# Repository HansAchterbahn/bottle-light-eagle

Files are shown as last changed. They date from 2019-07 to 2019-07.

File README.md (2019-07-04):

# Bottle Light: Eagle Data (PCB)

Bottle Light is a coaster that make your bottle glow in all colors of the rainbow. More information about the Bottle Light project can be found in the main repository: [bottle-light](https://github.com/HansAchterbahn/bottle-light)

In this Repository you can find the shematics and board layouts created in Eagle.

*Fork me and have fun!*

## Schematic

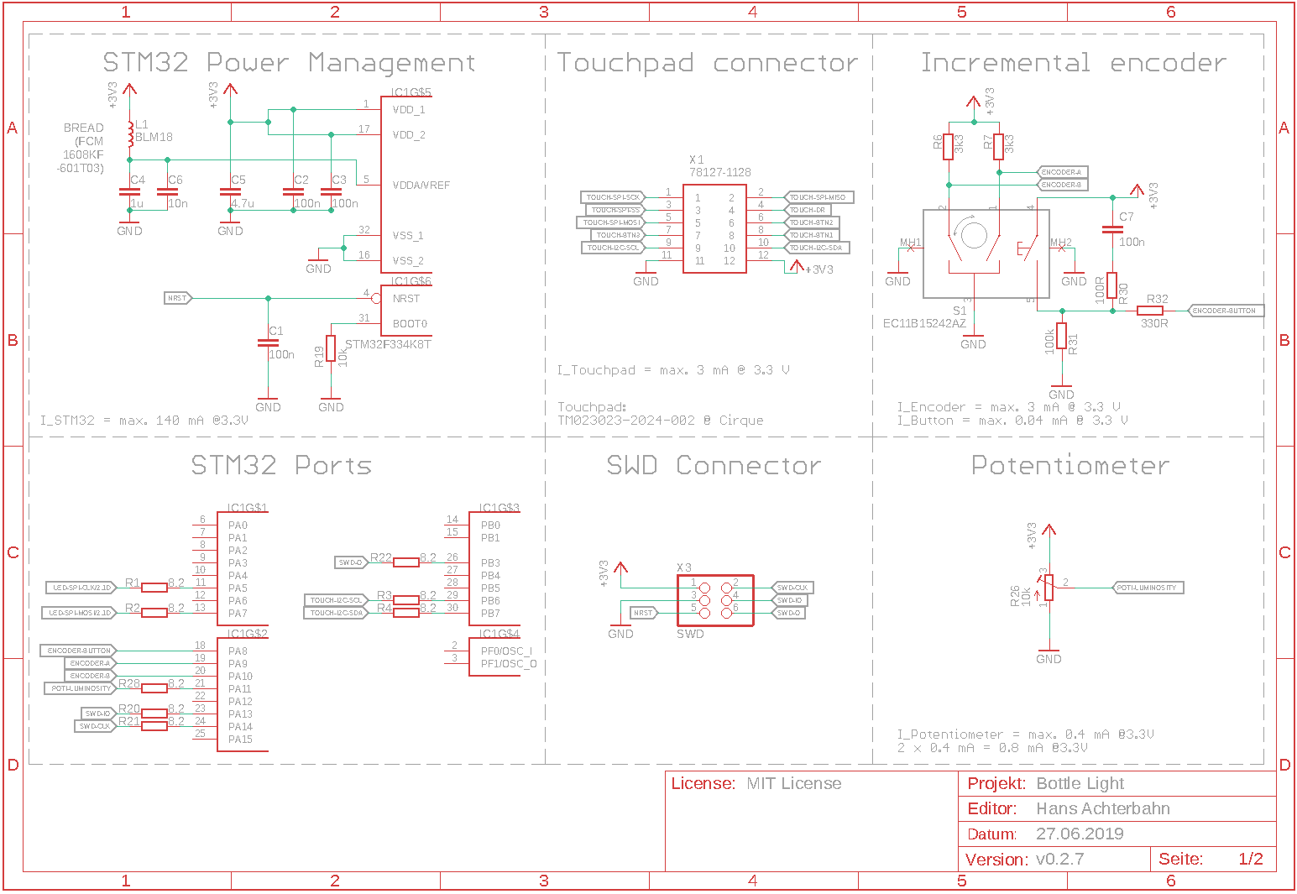
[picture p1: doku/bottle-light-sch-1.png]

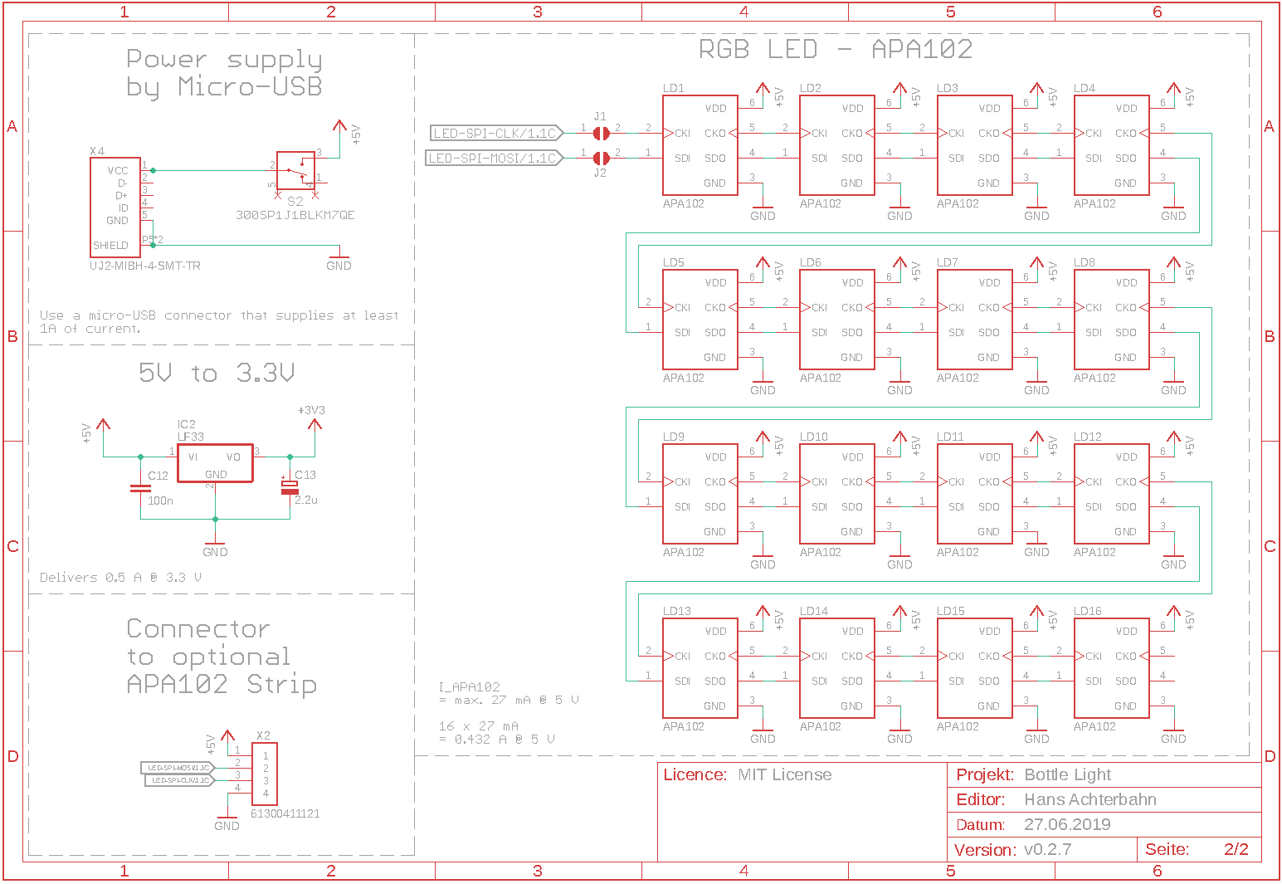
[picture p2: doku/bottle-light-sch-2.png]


## Board

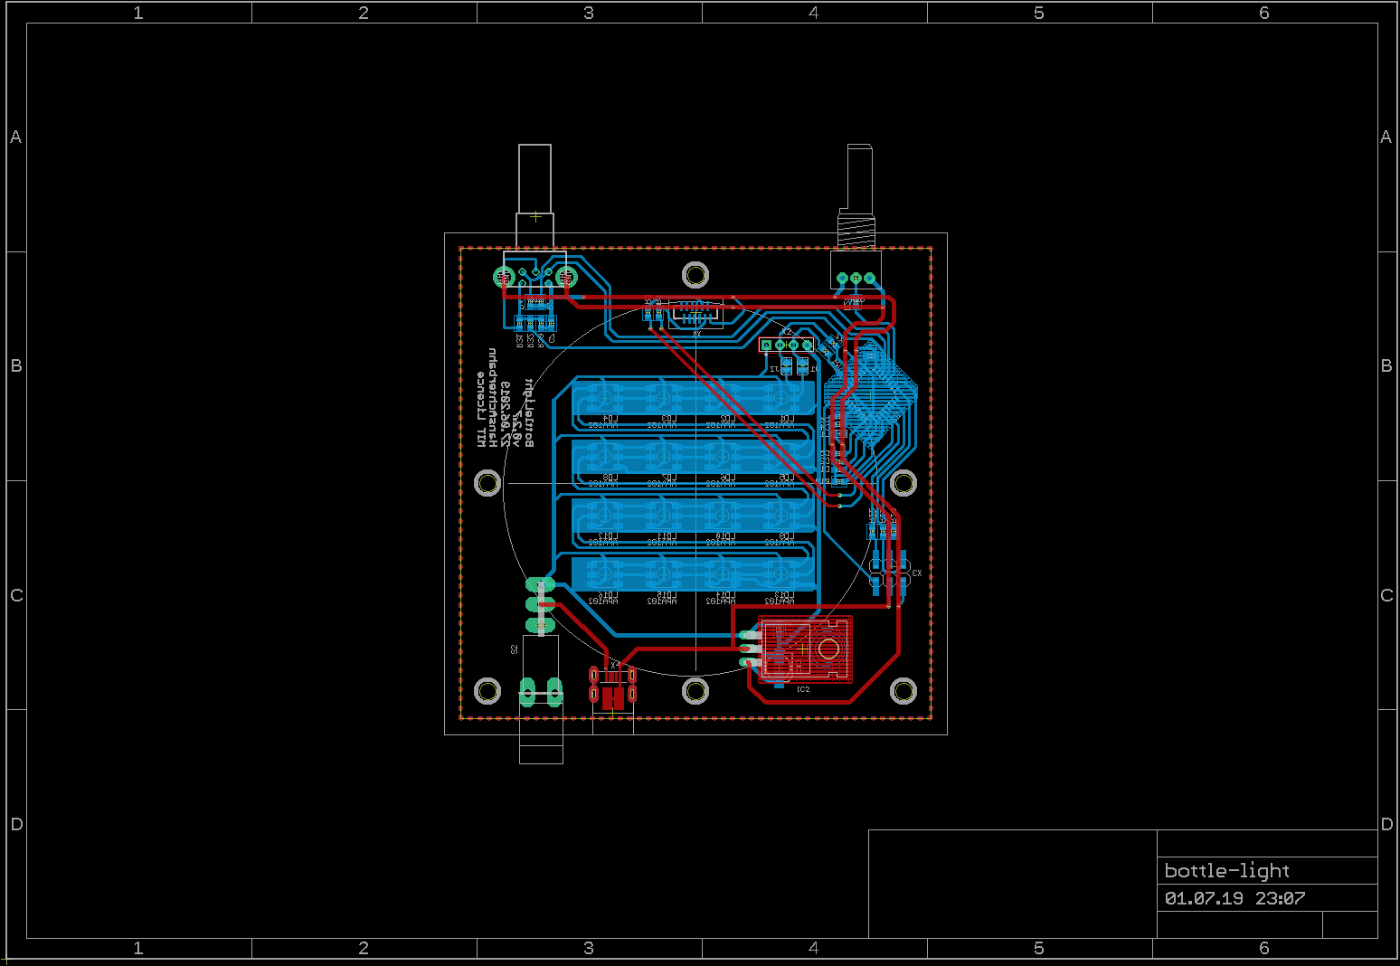
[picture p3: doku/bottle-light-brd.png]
LED Ring Board
 

## 3D View (Fusion360)

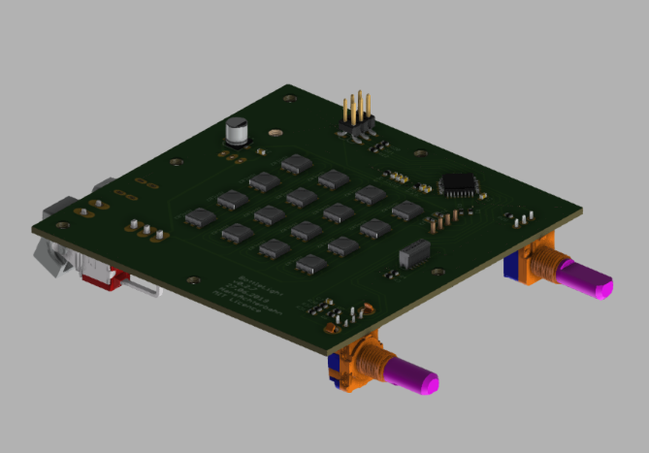
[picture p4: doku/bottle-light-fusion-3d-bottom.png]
LED Ring 3D top site

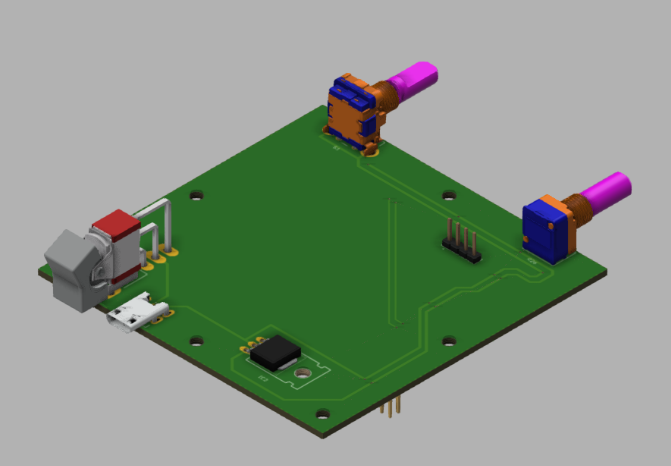
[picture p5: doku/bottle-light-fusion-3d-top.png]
LED Ring 3D bottom site


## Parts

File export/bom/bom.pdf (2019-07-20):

bom

Qty | Value | Parts | MF | MFN | MOUSER | RS-ONLINE
2 | | J1, J2
1 100R | | R30 | Vishay | CRCW0603100RFKEAHP | 71-CRCW0603-100-E3 | 820-6748
1 100k | | R31 | Vishay | CRCW0603100KFKEA | 71-CRCW0603-100K-E3 | 678-9673
1 100n | | C7 | AVX | 0603YC104JAT2A | 581-0603YC104J | 391-246
1 100n | | C12
3 100n | | C1, C2, C3 | | | | 391-246
1 10k | | R19
1 10k | | R26 | ALPS | RK097111080R | 688-RK097111080R | 729-3458
1 10n | | C6 | | | | 264-4595
1 1u | | C4 | | | | 435-1403
1 2.2u | | C13
1 300SP1J1BLKM7QE | | S2 | E-Switch | 300SP1J1BLKM7QE | 612-300SP1J1BLKM7QE | -
1 330R | | R32 | Vishay | CRCW0603330RFKEA | 71-CRCW0603-330-E3 | 679-0226
2 3k3 | | R6, R7 | Vishay | CRCW06032K70FKEAC | 71-CRCW06032K70FKEAC-
1 4.7u | | C5 | | | | 691-1164
1 | 61300411121 X2 | | | 61300411121
1 78127-1128 | | X1 | Molex | 78127-1128 | 538-78127-1128
8 8.2 | | R1, R2, R3, R4, R20, R21, R22, R28 | | | | 904-5027
16 APA102 | | LD1 … LD16
1 BLM18 | | L1 | Murata | BLM18KG601SN1D | 81-BLM18KG601SN1D | 747-4720
1 EC11B15242AZ | | S1 | ALPS | EC11B15242AZ | 688-EC11B15242AE
1 LF33 | | IC2
1 STM32F334K8T | | IC1 | ST | STM32F334K8T
1 SWD | | X3 | Harwin | M20-8760342 | 855-M20-8760342 | 681-2880
1 UJ2-MIBH-4-SMT-TR | | X4

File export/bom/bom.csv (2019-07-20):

Qty | Value | Device | Package | Parts | Description | ALLIED_NUMBER | ALLIED_PRICE-STOCK | CREATED_BY | DESCRIPTION | DIGI_KEY_PART_NUMBER | HEIGHT | MANUFACTURER | MF | MFN | MOUSER | RS-ONLINE
2 |  | SJ | SJ | J1, J2 | SMD solder JUMPER
1 | 100R | R-EU_R0603 | R0603 | R30 | RESISTOR, European symbol |  |  |  |  |  |  |  | Vishay | CRCW0603100RFKEAHP | 71-CRCW0603-100-E3 | 820-6748
1 | 100k | R-EU_R0603 | R0603 | R31 | RESISTOR, European symbol |  |  |  |  |  |  |  | Vishay | CRCW0603100KFKEA | 71-CRCW0603-100K-E3 | 678-9673
1 | 100n | C-EUC0603 | C0603 | C7 | CAPACITOR, European symbol |  |  |  |  |  |  |  | AVX | 0603YC104JAT2A | 581-0603YC104J | 391-246
1 | 100n | C-EUC0603 | C0603 | C12 | CAPACITOR, European symbol
3 | 100n | C-EUC0603K | C0603K | C1, C2, C3 | CAPACITOR, European symbol |  |  |  |  |  |  |  |  |  |  | 391-246
1 | 10k | R-EU_R0603 | R0603 | R19 | RESISTOR, European symbol
1 | 10k | RK0971110 | RK0971110 | R26 | Potentiometer |  |  |  |  |  |  |  | ALPS | RK097111080R | 688-RK097111080R | 729-3458
1 | 10n | C-EUC0603K | C0603K | C6 | CAPACITOR, European symbol |  |  |  |  |  |  |  |  |  |  | 264-4595
1 | 1u | C-EUC0603K | C0603K | C4 | CAPACITOR, European symbol |  |  |  |  |  |  |  |  |  |  | 435-1403
1 | 2.2u | CPOL-EU153CLV-0505 | 153CLV-0505 | C13 | POLARIZED CAPACITOR, European symbol
1 | 300SP1J1BLKM7QE | 300SP1J1BLKM7QE | 300SP1J1BLKM7QE | S2 | E-Switch - 300 Series Rocker Switch |  |  |  |  |  |  |  | E-Switch | 300SP1J1BLKM7QE | 612-300SP1J1BLKM7QE | -
1 | 330R | R-EU_R0603 | R0603 | R32 | RESISTOR, European symbol |  |  |  |  |  |  |  | Vishay | CRCW0603330RFKEA | 71-CRCW0603-330-E3 | 679-0226
2 | 3k3 | R-EU_R0603 | R0603 | R6, R7 | RESISTOR, European symbol |  |  |  |  |  |  |  | Vishay | CRCW06032K70FKEAC | 71-CRCW06032K70FKEAC | -
1 | 4.7u | C-EUC0603K | C0603K | C5 | CAPACITOR, European symbol |  |  |  |  |  |  |  |  |  |  | 691-1164
1 | 61300411121 | 61300411121 | 61300411121 | X2 | CONN HEADER VERT 4POS 2.54MM |  |  | PCBLayout.com |  | 732-5317-ND |  | Wurth Electronics Inc. |  | 61300411121
1 | 78127-1128 | 78127-1128 | 781271128 | X1 | FFC & FPC Connectors 0.5 FPC CONN. VERTIC AL SMT NON-ZIF 12CKT | 70714305 | https://www.alliedelec.com/molex-incorporated-78127-1128/70714305/ |  | FFC & FPC Connectors 0.5 FPC CONN. VERTIC AL SMT NON-ZIF 12CKT |  | 4mm |  | Molex | 78127-1128 | 538-78127-1128
8 | 8.2 | R-EU_R0603 | R0603 | R1, R2, R3, R4, R20, R21, R22, R28 | RESISTOR, European symbol |  |  |  |  |  |  |  |  |  |  | 904-5027
16 | APA102 | APA102APA102C-5050 | APA102C-5050 | LD1 … LD16 | DotStar Micro LEDs (APA102–2020)- Smart SMD RGB LED - 100 pack
1 | BLM18 | INDUCTOR/FERRITE-BEAD'0603' | L0603 | L1 |  |  |  |  |  |  |  |  | Murata | BLM18KG601SN1D | 81-BLM18KG601SN1D | 747-4720
1 | EC11B15242AZ | EC11B15242AZ | EC11B15242AZ | S1 | Komponente von www.SamacSys.com geforkt: |  |  |  | Encoders 5 Volts Through Hole |  | 24mm |  | ALPS | EC11B15242AZ | 688-EC11B15242AE
1 | LF33 | 7805T | TO220H | IC2 | Positive VOLTAGE REGULATOR
1 | STM32F334K8T | STM32F334K8T | LQFP32-7X7 | IC1 | STM32 Mikrocontroller: STM32F334K8Tx |  |  |  |  |  |  |  | ST | STM32F334K8T
1 | SWD | PINHD-2X3_2.54-SMD | 2X03SMD | X3 | PIN HEADER |  |  |  |  |  |  |  | Harwin | M20-8760342 | 855-M20-8760342 | 681-2880
1 | UJ2-MIBH-4-SMT-TR | UJ2-MIBH-4-SMT-TRCUIINC_UJ2-MIBH-4-SMT-TR-2 | CUIINC_UJ2-MIBH-4-SMT-TR-2 | X4 | Micro B Type 5 Pin Horizontal 30 µin Plating SMT USB Jack 2.0

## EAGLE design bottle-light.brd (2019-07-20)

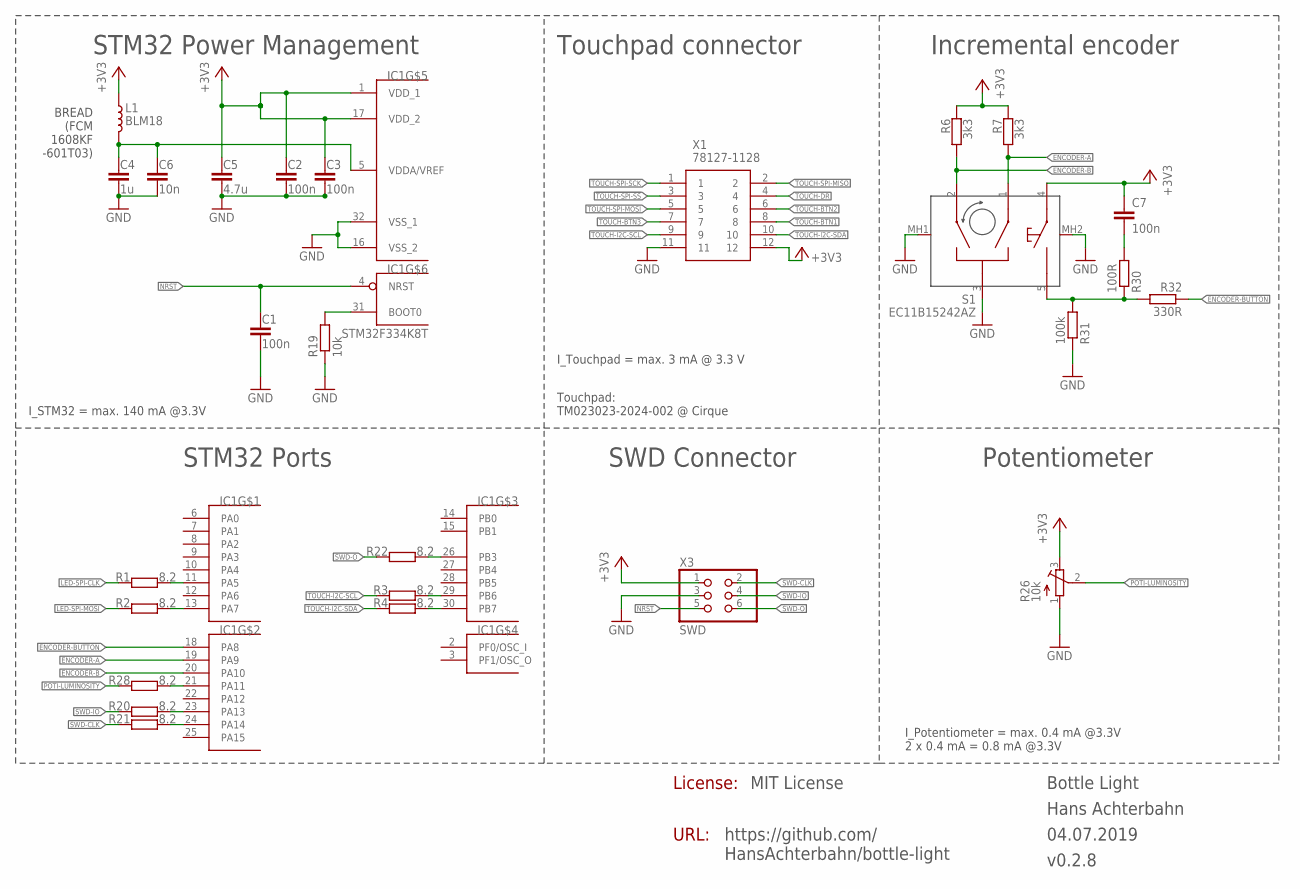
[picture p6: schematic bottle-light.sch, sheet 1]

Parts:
C1, C2, C3: 100n; C0603K
C4: 1u; C0603K
C5: 4.7u; C0603K
C6: 10n; C0603K
C7: 100n; C0603; MOUSER 581-0603YC104J
IC1: STM32F334K8T; LQFP32-7X7
L1: BLM18; L0603; MOUSER 81-BLM18KG601SN1D
R1, R2, R3, R4, R20, R21, R22, R28: 8.2; R0603
R6, R7: 3k3; R0603; MOUSER 71-CRCW06032K70FKEAC
R19: 10k; R0603
R26: 10k; RK0971110
R30: 100R; R0603; MOUSER 71-CRCW0603-100-E3
R31: 100k; R0603; MOUSER 71-CRCW0603-100K-E3
R32: 330R; R0603; MOUSER 71-CRCW0603-330-E3
S1: EC11B15242AZ; MPN EC11B15242AZ; MOUSER 688-EC11B15242AE
X1: 78127-1128; 781271128
X3: SWD; 2X03SMD; MOUSER 855-M20-8760342

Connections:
!TOUCH-SPI-SS: X1.3
+3V3: C2.1, C3.1, C5.1, C7.1, IC1.1 (VDD_1), IC1.17 (VDD_2), L1.1, R6.1, R7.1, R26.3 (E), S1.4 (D), X1.12, X3.1; also elsewhere on the board
ENCODER-A: IC1.19 (PA9), R7.2, S1.1 (A)
ENCODER-B: IC1.20 (PA10), R6.2, S1.2 (B)
ENCODER-BUTTON: IC1.18 (PA8), R32.1
GND: C1.2, C2.2, C3.2, C4.2, C5.2, C6.2, IC1.16 (VSS_2), IC1.32 (VSS_1), R19.1, R26.1 (A), R31.1, S1.3 (C), S1.MH1, S1.MH2, X1.11, X3.3; also elsewhere on the board
LED-SPI-CLK: R1.1; also elsewhere on the board
LED-SPI-MOSI: R2.1; also elsewhere on the board
unnamed: IC1.24 (PA14), R21.2
unnamed: IC1.11 (PA5), R1.2
unnamed: IC1.13 (PA7), R2.2
unnamed: IC1.29 (PB6), R3.2
unnamed: IC1.30 (PB7), R4.2
unnamed: IC1.21 (PA11), R28.2
unnamed: C4.1, C6.1, IC1.5 (VDDA/VREF), L1.2
unnamed: IC1.31 (BOOT0), R19.2
unnamed: IC1.23 (PA13), R20.2
unnamed: IC1.26 (PB3), R22.2
unnamed: R30.1, R31.2, R32.2, S1.5 (E)
unnamed: C7.2, R30.2
NRST: C1.1, IC1.4 (NRST), X3.5
POTI-LUMINOSITY: R26.2 (S), R28.1
SWD-CLK: R21.1, X3.2
SWD-IO: R20.1, X3.4
SWD-O: R22.1, X3.6
TOUCH-BTN1: X1.8
TOUCH-BTN2: X1.6
TOUCH-BTN3: X1.7
TOUCH-DR: X1.4
TOUCH-I2C-SCL: R3.1, X1.9
TOUCH-I2C-SDA: R4.1, X1.10
TOUCH-SPI-MISO: X1.2
TOUCH-SPI-MOSI: X1.5
TOUCH-SPI-SCK: X1.1

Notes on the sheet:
STM32 Power Management
STM32 Ports
Incremental encoder
SWD Connector
Potentiometer
I_Potentiometer = max. 0.4 mA @3.3V 2 x 0.4 mA = 0.8 mA @3.3V
I_STM32 = max. 140 mA @3.3V
License:
BREAD (FCM 1608KF -601T03)
Touchpad connector
I_Touchpad = max. 3 mA @ 3.3 V
Touchpad: TM023023-2024-002 @ Cirque
https://github.com/ HansAchterbahn/bottle-light
URL:

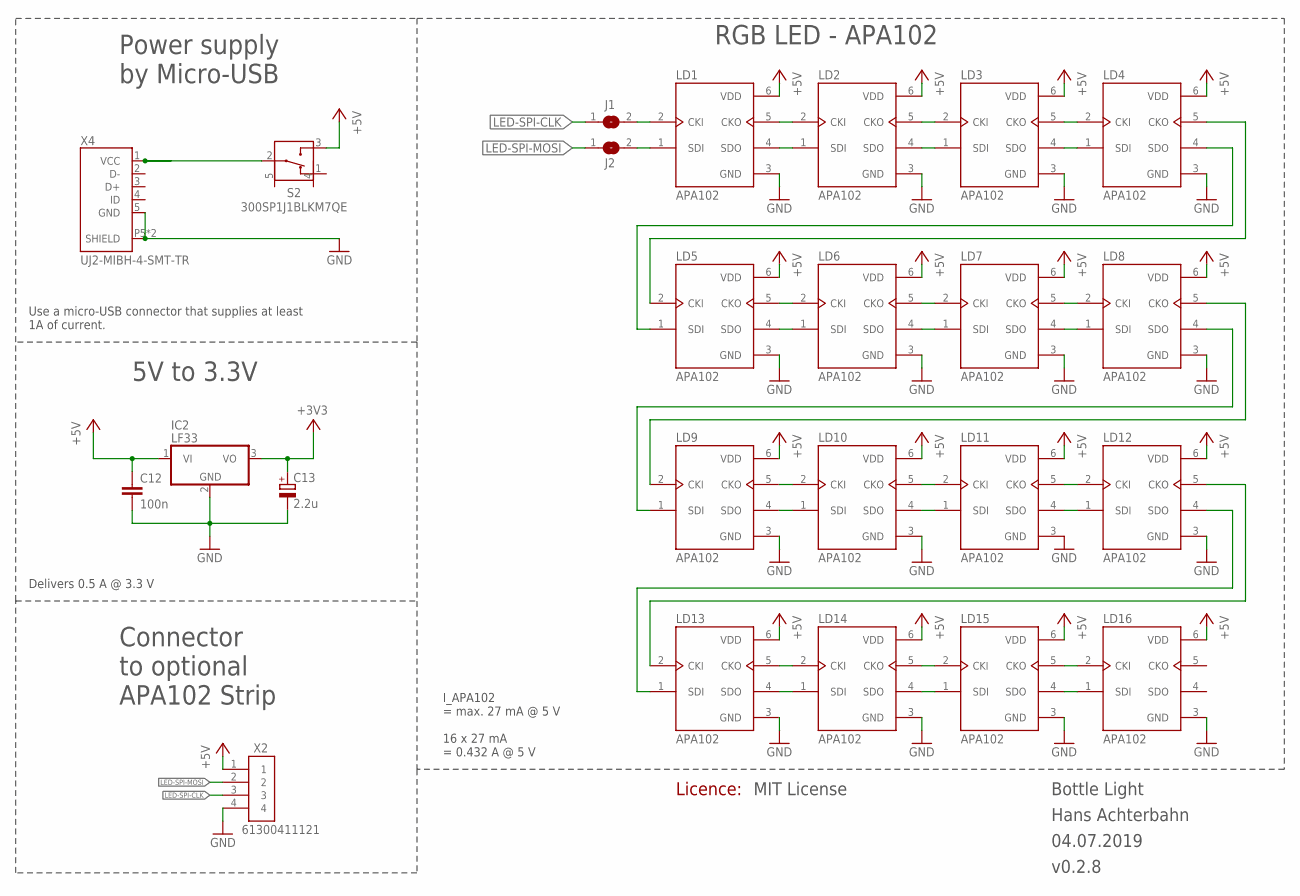
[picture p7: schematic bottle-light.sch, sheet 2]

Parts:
C12: 100n; C0603
C13: 2.2u; 153CLV-0505
IC2: LF33; TO220H
J1, J2: SJ
LD1, LD2, LD3, LD4, LD5, LD6, LD7, LD8, LD9, LD10, LD11, LD12, LD13, LD14, LD15, LD16: APA102; APA102C-5050
S2: 300SP1J1BLKM7QE
X2: 61300411121
X4: UJ2-MIBH-4-SMT-TR; CUIINC_UJ2-MIBH-4-SMT-TR-2; MOUSER 490-UJ2-MIBH-4-SMT

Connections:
5V-IN: S2.2 (IN), X4.1 (VCC)
+3V3: C13.+, IC2.3 (VO); also elsewhere on the board
+5V: C12.1, IC2.1 (VI), LD1.6 (VDD), LD2.6 (VDD), LD3.6 (VDD), LD4.6 (VDD), LD5.6 (VDD), LD6.6 (VDD), LD7.6 (VDD), LD8.6 (VDD), LD9.6 (VDD), LD10.6 (VDD), LD11.6 (VDD), LD12.6 (VDD), LD13.6 (VDD), LD14.6 (VDD), LD15.6 (VDD), LD16.6 (VDD), S2.3 (OUT1), X2.1
GND: C12.2, C13.-, IC2.2 (GND), LD1.3 (GND), LD2.3 (GND), LD3.3 (GND), LD4.3 (GND), LD5.3 (GND), LD6.3 (GND), LD7.3 (GND), LD8.3 (GND), LD9.3 (GND), LD10.3 (GND), LD11.3 (GND), LD12.3 (GND), LD13.3 (GND), LD14.3 (GND), LD15.3 (GND), LD16.3 (GND), X2.4, X4.5 (GND), X4.P5 (SHIELD), X4.P6 (SHIELD); also elsewhere on the board
LED-SPI-CLK: J1.1, X2.3; also elsewhere on the board
LED-SPI-MOSI: J2.1, X2.2; also elsewhere on the board
unnamed: J1.2, LD1.2 (CKI)
unnamed: J2.2, LD1.1 (SDI)
unnamed: LD1.5 (CKO), LD2.2 (CKI)
unnamed: LD1.4 (SDO), LD2.1 (SDI)
unnamed: LD2.5 (CKO), LD3.2 (CKI)
unnamed: LD2.4 (SDO), LD3.1 (SDI)
unnamed: LD3.5 (CKO), LD4.2 (CKI)
unnamed: LD3.4 (SDO), LD4.1 (SDI)
unnamed: LD4.5 (CKO), LD5.2 (CKI)
unnamed: LD4.4 (SDO), LD5.1 (SDI)
unnamed: LD5.5 (CKO), LD6.2 (CKI)
unnamed: LD5.4 (SDO), LD6.1 (SDI)
unnamed: LD6.5 (CKO), LD7.2 (CKI)
unnamed: LD6.4 (SDO), LD7.1 (SDI)
unnamed: LD7.5 (CKO), LD8.2 (CKI)
unnamed: LD7.4 (SDO), LD8.1 (SDI)
unnamed: LD8.5 (CKO), LD9.2 (CKI)
unnamed: LD8.4 (SDO), LD9.1 (SDI)
unnamed: LD9.5 (CKO), LD10.2 (CKI)
unnamed: LD9.4 (SDO), LD10.1 (SDI)
unnamed: LD10.5 (CKO), LD11.2 (CKI)
unnamed: LD10.4 (SDO), LD11.1 (SDI)
unnamed: LD11.5 (CKO), LD12.2 (CKI)
unnamed: LD11.4 (SDO), LD12.1 (SDI)
unnamed: LD12.5 (CKO), LD13.2 (CKI)
unnamed: LD12.4 (SDO), LD13.1 (SDI)
unnamed: LD13.5 (CKO), LD14.2 (CKI)
unnamed: LD13.4 (SDO), LD14.1 (SDI)
unnamed: LD14.5 (CKO), LD15.2 (CKI)
unnamed: LD14.4 (SDO), LD15.1 (SDI)
unnamed: LD15.5 (CKO), LD16.2 (CKI)
unnamed: LD15.4 (SDO), LD16.1 (SDI)

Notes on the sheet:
Power supply by Micro-USB
5V to 3.3V
RGB LED - APA102
Delivers 0.5 A @ 3.3 V
Use a micro-USB connector that supplies at least 1A of current.
I_APA102 = max. 27 mA @ 5 V 16 x 27 mA = 0.432 A @ 5 V
Licence:
Connector to optional APA102 Strip

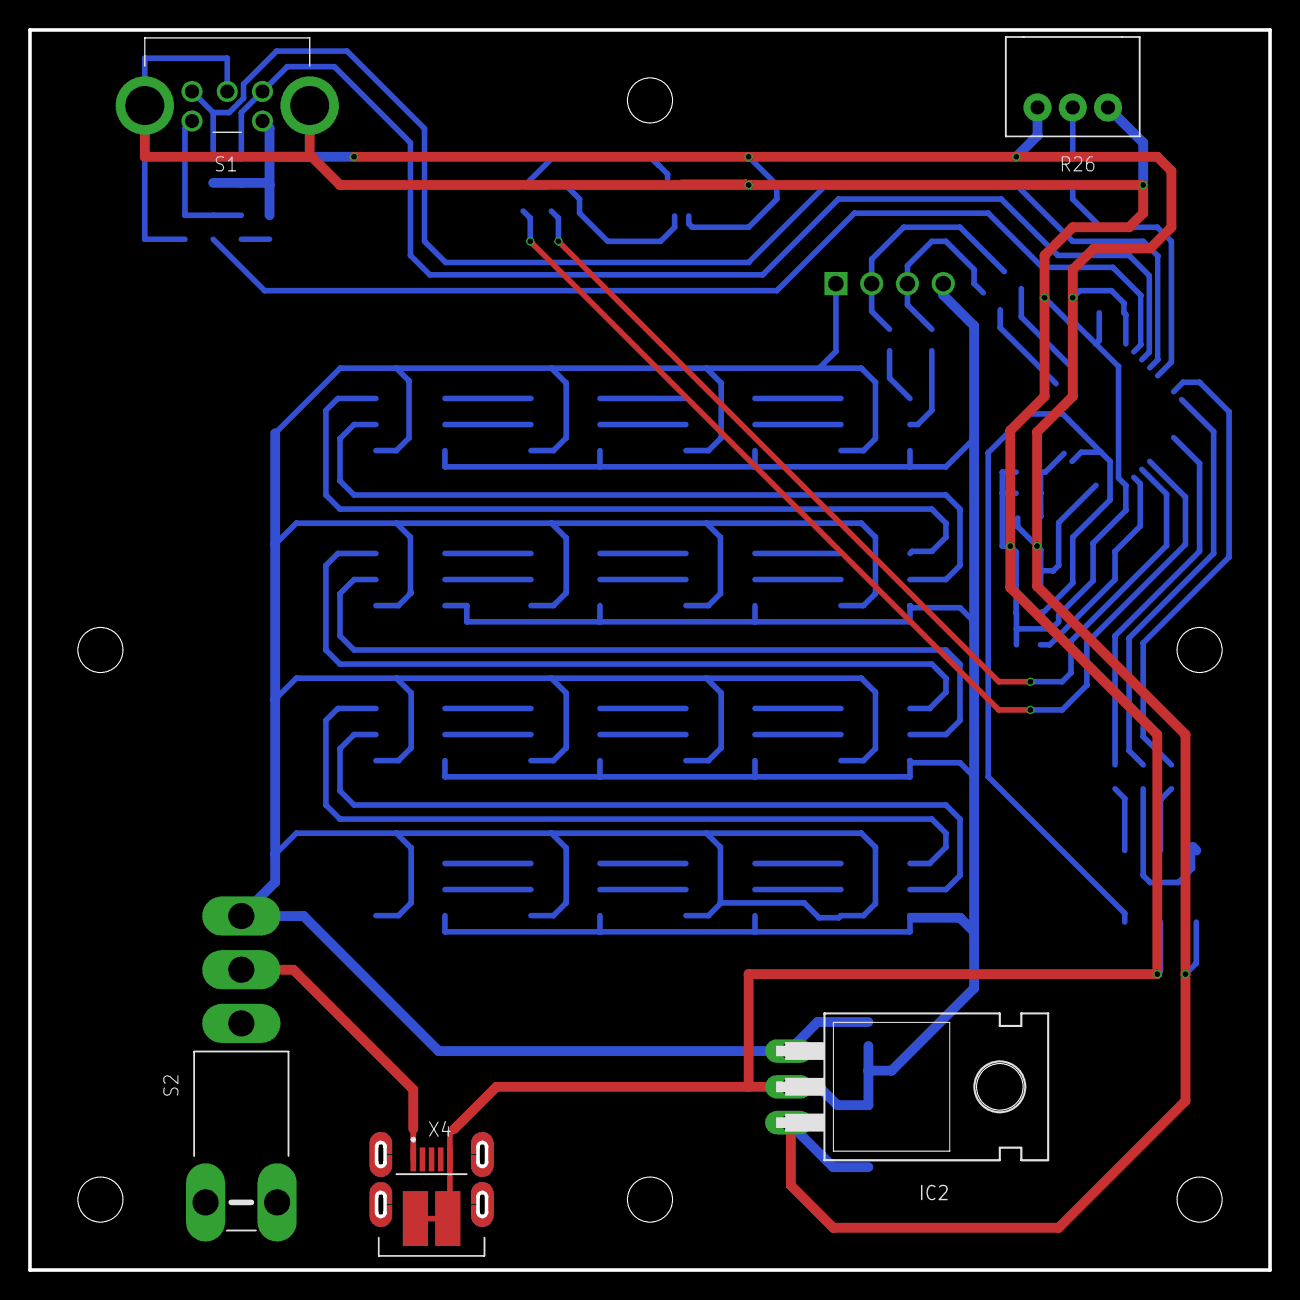
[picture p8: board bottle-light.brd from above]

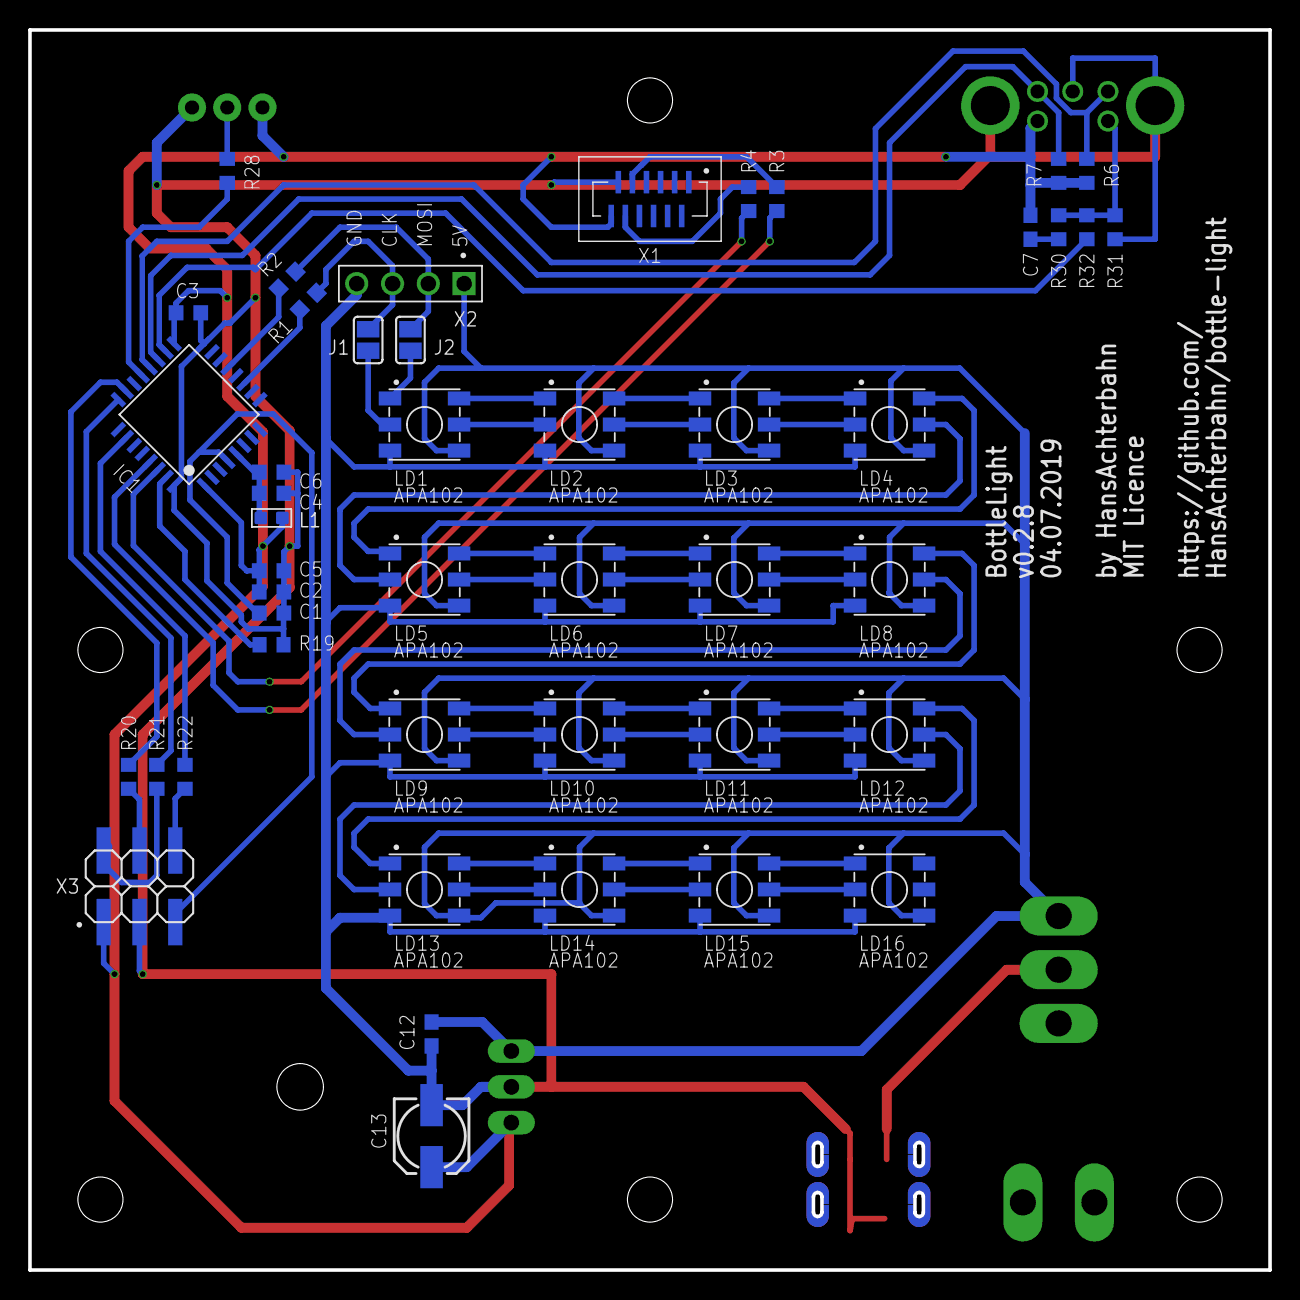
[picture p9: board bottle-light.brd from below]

Board: 2 copper layers, 88.0 x 88.0 mm, 52 parts (46 on the bottom side), 60 nets.

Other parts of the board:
U$1: A4L-LOC

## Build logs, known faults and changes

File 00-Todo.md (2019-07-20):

# Todo

## Schematic

* [ ] PotiLuminosity is connectet to a ADC interupt pin but not to an single ended adc -> pin musst be changed
* [ ] IC2 LF33 should be changed to a SMD device and put to bottom
* [ ] X4 USB connector should put to bottom
* [ ] S2 should be changed to a horizontal lever to decrease height
* [ ] it could be nice to add second X2 connector after the APA102 LEDs
* [ ] add a 3.3 V to 5 V driver for MOSI and SCLK
* [ ] add pins at the edges of the pcb to use them as holder in a laser-cut box
* [ ] change to a STM32F4 microcontroller to get a real random number genearator -> maybe the STM32F415RG?
* [ ] change programmer connector to FFC type
* [ ] Add an additional potentiometer to have the option of not assembling the touchpad

## Board

* [ ] the SWD Connector needs signal labeling
* [ ] it could be elegant to move S1, S2 and R26 to bottom
* [ ] footprint of APA102 is a bit to large -> change it

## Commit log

2017-07-02 v0.1.0 created new projet 'bottle-light'
    [bottle-light.brd, bottle-light.sch]
2017-07-03 v0.1.1 worked on circuit diagram - new push buttons - new on/off button
    [bottle-light.brd, bottle-light.sch]
2017-07-09 v0.1.2 Put in new devices and began routing pcb - new potis - made groundplane size for case - placed leds, potis and switch
    [bottle-light.brd, bottle-light.sch]
2017-07-09 v0.1.3 schematic finished and board is routed - added new buttons - added swd debugger port - added battery pack - changed stm32 pinning - changed dc power supply port - removed reset button - added 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
    [bottle-light.brd, bottle-light.sch]
2018-10-12 v0.1.4 new schematic arrangement
    [bottle-light.sch]
2019-01-05 v0.2.0 Neue LEDs hinzugefügt: APA102
    [bottle-light.brd, bottle-light.sch]
2019-01-05 v0.2.1 Die neuen LEDs positioniert
    [bottle-light.brd, bottle-light.sch]
2019-06-08 v0.2.2 LEDs connected and port for touch pad added
    [bottle-light.brd, bottle-light.sch]
2019-06-09 v0.2.3 pinout and connection of touch pad to STM32 | changed library of buttons and potentiometers | added polygon on top and bottom| changed Micro-USB position
    [bottle-light.brd, bottle-light.sch]
2019-06-10 v0.2.4 Device of Micro-USB connector was defect -> repaired | removed buttons and color potentiometer | added incremental encoder | connected touch pad connector to I2C of STM32 | added MIT license |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
    [bottle-light.brd, bottle-light.sch]
2019-06-11 v0.2.5 changed luminosity potentiometer | potentiometer and incremental encoder set to correct position
    [bottle-light.brd, bottle-light.sch]
2019-06-11 v0.2.6 STM32 rotated 45 degrees to optimize wire routing.
    [bottle-light.brd, bottle-light.sch]
2019-06-13 v0.2.7 new power switch | new restricted areas | optimized wires | checked positions of all components mounted at the edge | optimized polygon
    [bottle-light.brd, bottle-light.sch]
2019-06-19 optimized text positions | added 2 jumpers for easy usage of additional LED strip
    [bottle-light.brd, bottle-light.sch]
2019-06-27 Vias verkleinert | 3D Modelle hinzugefügt | auf Fusion gepusht
    [bottle-light.brd, bottle-light.sch]
2019-06-27 Gerber Daten erzeugt und 5 weiße Prototyp + Stencil bei https://jlcpcb.com bestellt ($ 20.46)
    [copper_bottom.gbr, copper_top.gbr, drill_1_16.xln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]
2019-06-27 Fusion sync
    [bottle-light.brd]
2019-07-01 Update README | added images of schematic, board and 3D view
    [bottle-light.brd]
2019-07-04 changed some footprint drawings
    [bottle-light.brd, bottle-light.sch]
2019-07-20 added bom files
    [bom.csv, bom.ods]
2019-07-20 added attributes to UJ2-MIBH-4-SMT-TR
    [bottle-light.brd, bottle-light.sch]

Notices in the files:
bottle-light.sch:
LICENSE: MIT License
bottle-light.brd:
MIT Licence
